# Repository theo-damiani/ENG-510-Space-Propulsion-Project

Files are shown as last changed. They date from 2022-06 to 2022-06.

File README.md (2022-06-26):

## SPACE PROPULSION – ENG-510 - Course project

### Main objectives:

- Practical application of the course content.
- Development of a **1.5 stage launcher**, i.e. 1 core + booster(s).
- Propulsion systems based on liquid propulsion (water + air pressure).
- Launcher shall integrate a recovery system (parachutes)
- Test equipment will be provided for propulsion systems testing and systems qualification. Ground station will also be provided.

### 31.5.2022: Lift-off:

<p align="center">
  Final Rocket
</p>

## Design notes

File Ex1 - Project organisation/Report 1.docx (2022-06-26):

- Launcher System (Technical coherence, requirement engineering) Romane
- Core Stage (Propulsion, mechanical engineering) Valentin
- Booster Stage (Propulsion, separation engineering, mechanism) Bruno
- Recovery System (Software, electrical engineering, mechanism) Noah
- Ground System I/F (Interface management, mechanism, certification) Théo

Main requirements (must be verifiable):

- The vehicle should reach a maximum apogee of 200m
- The main core stage should land under a parachute
- The booster should detach from the center core after their burn
- The propulsion should be only done by water and air

Mission phases - Concept of operation:

- Avionics powers in
- Countdown
- Liftoff
- End of burn of boosters
- Booster separation
- Apogee reached of the center core
- Center core’s parachute deployment
- Landing of the center core

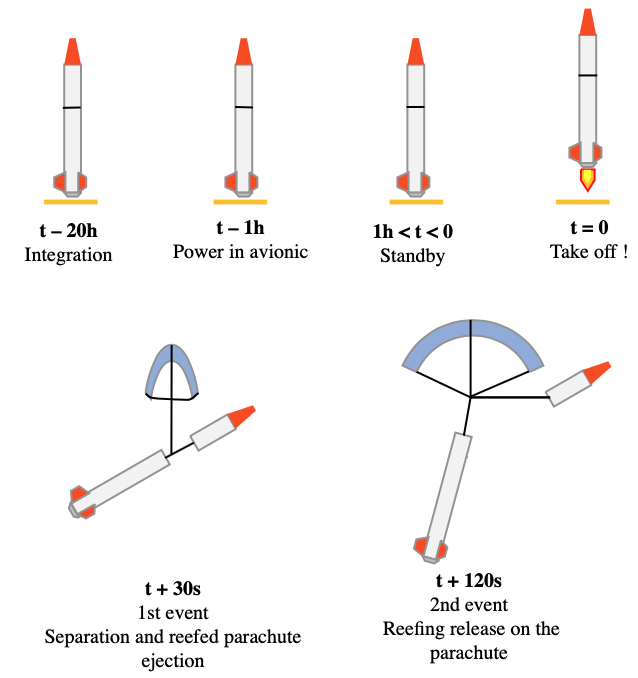
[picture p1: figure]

(to update, in progress… )

Verification to be performed

Schedule with short description of main task

08.03.2022 - Organization of the Project (Phase 0)

- Mission characterization
- Mission evaluation
- Requirements Definition
- High level specifications

22.3.2022 - Define Ground I/F

5.4.2022 - Performance Analysis

26.4.2022 -Verification Plan

10.5.2022 - Qualification Review

24.5.2022 - Lift-off

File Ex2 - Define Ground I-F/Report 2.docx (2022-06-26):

How many stages / bottles do we need ?

- main stage
- 3 bottles as side boosters

Which pressure do we foresee ?

- ca 10 bars (initial pressure)

Which Water mass is considered ?

How do you intend to fill the Water and when (on the launch pad) ?

Is there a need for a launch tower ?

Do we need a pressure measurement for your electrical system ?

Anything else ? Recovery ?

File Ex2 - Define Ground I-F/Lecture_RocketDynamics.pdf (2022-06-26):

# Rocket Dynamics

## - Forces on the Rockets - Drag - Rocket Stability - Rocket Equation - Specific Impulse - Rocket Motors

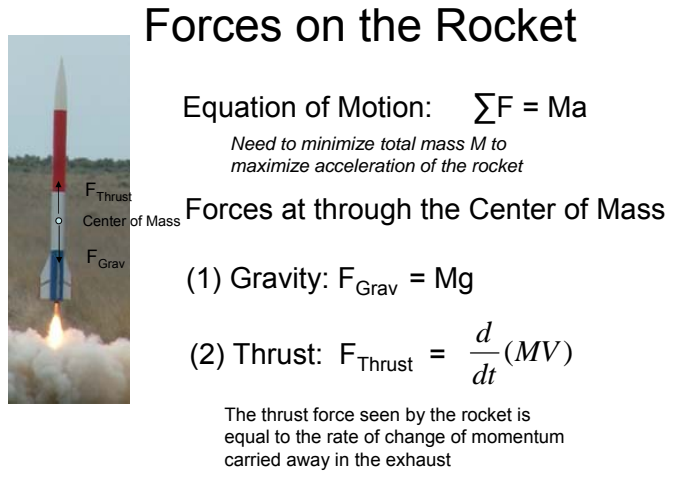
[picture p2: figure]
Forces on the Rocket; Equation of Motion:; (1) Gravity: FGrav = Mg; FGrav; (2) Thrust: FThrust =; (MV) dtd; FThrust; The thrust force seen by the rocket is equal to the rate of change of momentum carried away in the exhaust; Need to minimize total mass M to maximize acceleration of the rocket

## Center of MassForces at through the Center of Mass

## Thrust:

Assuming that the propellant speed is approximately constant then

## MPCE F

Thrust =

Where CE is the speed of the exhaust
is the rate of change propellant mass MP

In other words, how fast you go is dependent on
- the speed of the propellant
- the mass available in propellant

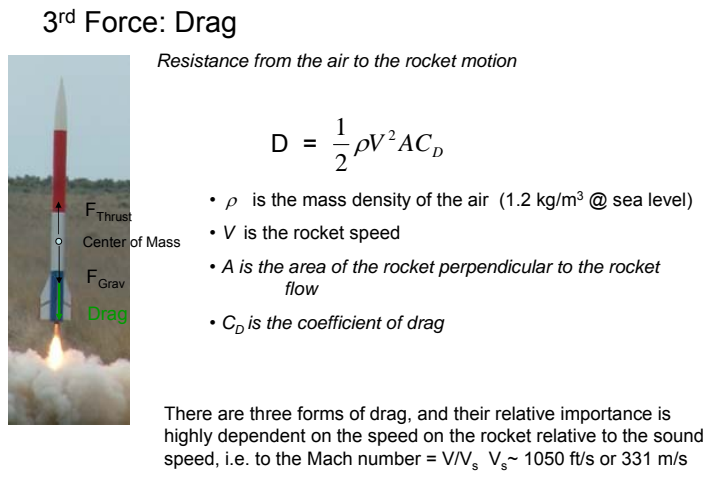
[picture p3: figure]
3rd Force: Drag; V ACD 2 21 D =; • V is the rocket speed; flow; • CD is the coefficient of drag; Center of Mass; FGrav; FThrust; Drag

- ρ is the mass density of the air (1.2 kg/m³ @ sea level)
- A is the area of the rocket perpendicular to the rocket

Resistance from the air to the rocket motion

There are three forms of drag, and their relative importance is highly dependent on the speed on the rocket relative to the sound speed, i.e. to the Mach number = V/Vs Vs~ 1050 ft/s or 331 m/s

# Types of Drag

### 1. Skin friction arises from the friction of the fluid against the

"skin" of the object that is moving through it. Skin friction arises from the interaction between the fluid and the skin of the body.

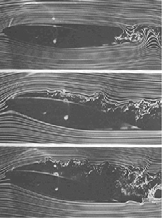
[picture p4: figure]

Rivets on skin surface add significantly to total drag at supersonic speeds

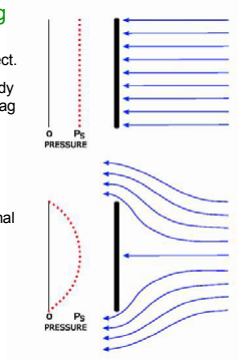
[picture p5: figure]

arises because of the form of the object. The general size and shape of the body is the most important factor in form drag Bodies with a larger apparent cross-section will have a higher drag than thinner bodies.
Sleek designs, or designs that are streamlined and change cross-sectional area gradually are also critical for achieving minimum form drag.

### (2) Pressure Drag or Form Drag

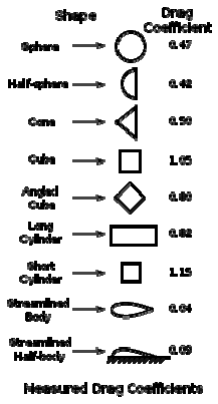
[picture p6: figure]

Drag coefficients for different shapes.

Elimination of vortices in the wake reduce the drag

### (2) Pressure Drag or Form Drag

## Wave drag

- is caused by the formation of shock waves around the aircraft which radiate away a considerable amount of energy producing enhanced drag
- Although shock waves are typically associated with supersonic flow, they can form at much lower speeds at areas on the aircraft where local airflow accelerates to supersonic speeds.

•The effect is typically seen at transonic speeds above about Mach 0.8, but it is possible to notice the problem at any speed over that of the critical Mach of that aircraft's wing.

•The magnitude peaks at about four times the normal subsonic drag.

•It is so powerful that it was thought for some time that engines would not be able to provide enough power to easily overcome the effect, which led to the concept of a "sound barrier".

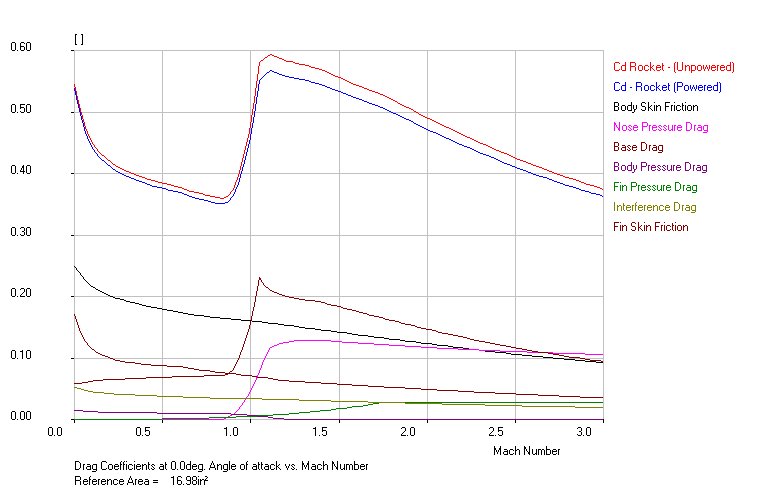
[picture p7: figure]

If you can get the rocket higher in altitude before going to high speed, effects from drag can be minimized

# Rocket Stability

### - Small perturbations will kick the rocket out of alignment - Active control of thrust vector could be used to correct these perturbations

– Heavy and Expensive

### - Passive control system through the use of fins - Success depends on the relative position of the Center of Pressure relative to the Center of Mass

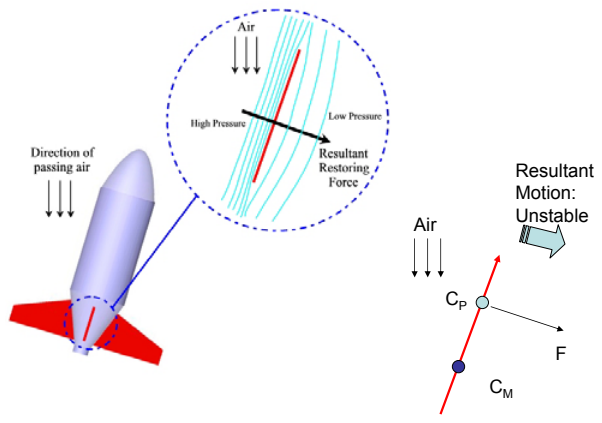
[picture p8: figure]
Air; Resultant Motion: Unstable
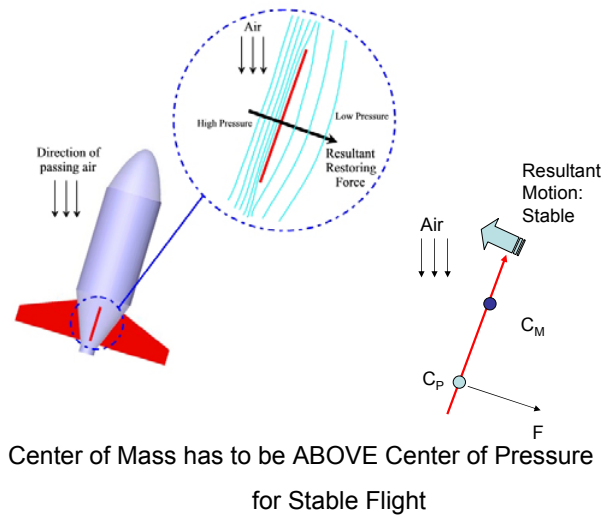
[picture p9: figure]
Air; Resultant Motion: Stable; for Stable Flight

### Center of Mass has to be ABOVE Center of Pressure

# Rocket Equation

Neglecting drag the equation of motion for the rocket is:
VE dt dM dt dV M | =

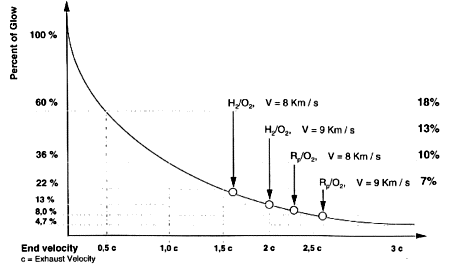
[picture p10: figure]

ò | ò =

M f

M

E

V

V | M

## dM dV V

0

2

1

## ln( ) ⁰

F

E | M
M ΔV =V | OR | exp( | ) ⁰
F | VE

V
M
M | Δ
= | -

Fraction of Payload becomes exponential small when required ΔV exceeds velocity of the propellant

Percentage Payload to Orbit Using
(1) H²/O2 and (2) Rp (highly refined kerosene)/O2

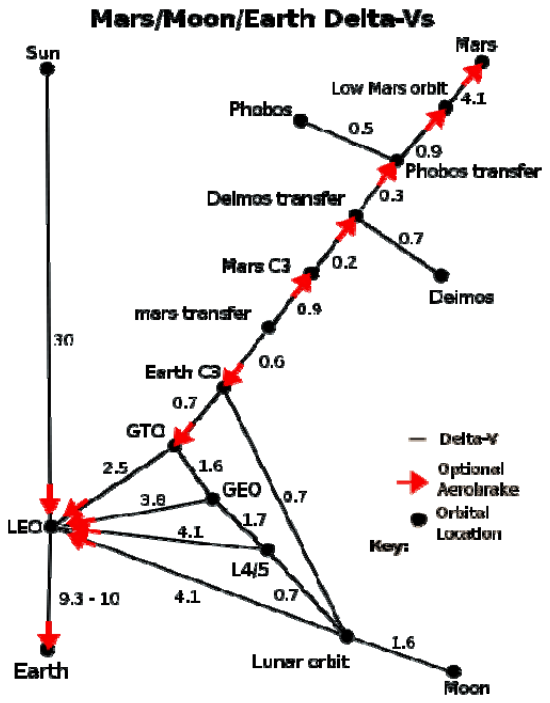
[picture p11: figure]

# Specific Impulse (Isp)

- is a way to describe the efficiency of rocket and jet engines.
- It represents the impulse (change in momentum) per unit of propellant.
- The higher the specific impulse, the less propellant is needed to gain a given amount of momentum.

g

V

## g mdt

## V mdt g mdt

## Fdt

Isp | E E = | = | = òò òò |

Specific impulse of various propulsion technologies

Ion thruster | 29,000 | 3,000 | 430
Bipropellant | 4,400 | 450 | 9.7
liquid rocket
Solid rocket | 2,500 | 250 | 3
Turbofan jet | 2,900 | 3,000 | ~0.05
engine | | | Energy per kg of exhaust (MJ/kg)
Specific
impulse
(s)

"Ve" exhaust
velocity
(m/s)

Engine

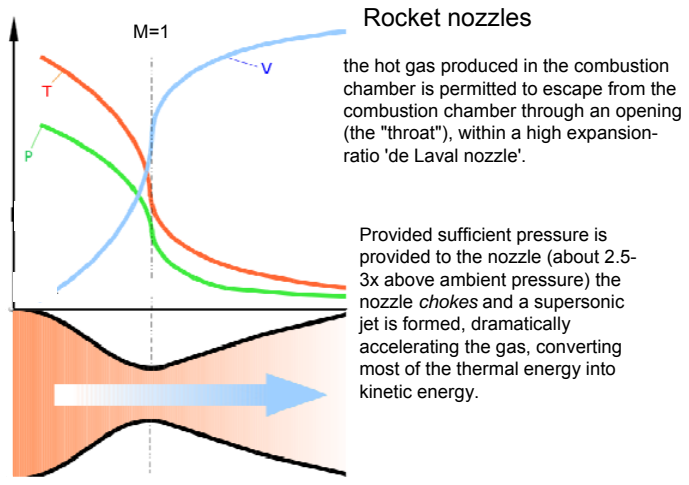
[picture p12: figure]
Rocket nozzles; the hot gas produced in the combustion chamber is permitted to escape from the combustion chamber through an opening; ratio 'de Laval nozzle'.; Provided sufficient pressure is provided to the nozzle (about 2.5- 3x above ambient pressure) the nozzle chokes and a supersonic jet is formed, dramatically accelerating the gas, converting most of the thermal energy into kinetic energy.

(the "throat"), within a high expansion-

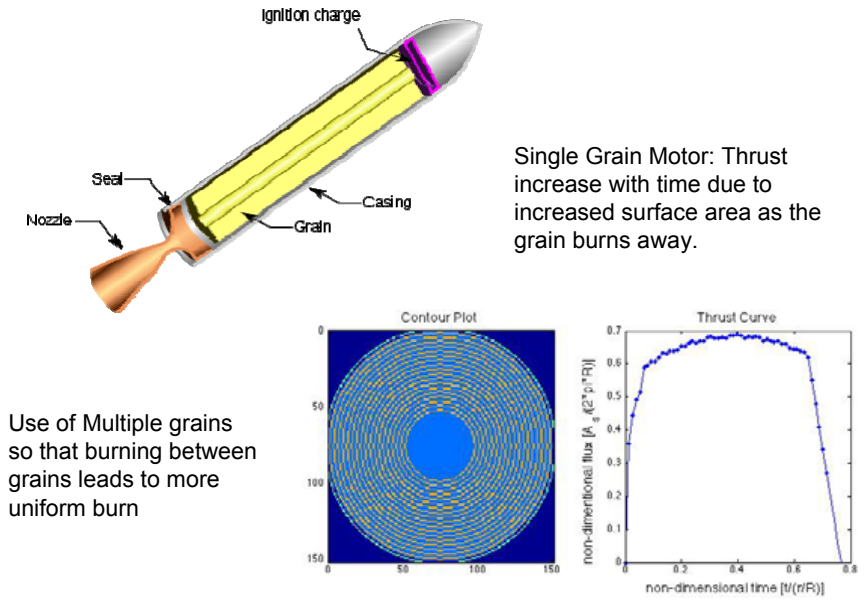
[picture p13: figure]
Single Grain Motor: Thrust increase with time due to increased surface area as the grain burns away.; Use of Multiple grains so that burning between grains leads to more uniform burn

Pumps needed for high performance are expensive to design, huge thermal fluxes across combustion chamber wall can impact reuse, failure modes include major explosions, a lot of plumbing is needed.

Up to ~99% efficient
combustion with
excellent mixture
control, throttleable,

Two fluid (typically liquid) propellants are
introduced through
injectors into combustion
chamber and burnt

Liquid
Bipropell
ant rocket

catalysts can be easily contaminated, monopropellants can detonate if contaminated or provoked, Isp is perhaps 1/3 of best liquids

Simple in concept,
throttleable, low
temperatures in
combustion chamber

Propellant such as
Hydrazine, Hydrogen
Peroxide or Nitrous
Oxide, flows over catalyst and exothermically
decomposes

Monopro
pellant
rocket

Some oxidisers are monopropellants, can explode in own right; mechanical failure of solid propellant can block nozzle (very rare with rubberised propellant), central hole widens over burn and negatively affects mixture ratio.

Quite simple, solid fuel
is essentially inert
without oxidiser, safer;
cracks do not escalate,
throttleable and easy to
switch off.

Separate oxidiser/fuel,
typically oxidiser is liquid and kept in a tank, the
other solid with central
hole

Hybrid
rocket

Once lit, extinguishing it is difficult although often possible, cannot be throttled in real time; handling issues from ignitable mixture, lower performance than liquid rockets, if grain cracks it can block nozzle with disastrous results, cracks burn and widen during burn.

Simple, often no
moving parts,
reasonably good mass
fraction, reasonable Isp.
A thrust schedule can
be designed into the
grain.

Ignitable, self sustaining solid fuel/oxidiser mixture ("grain") with central hole and nozzle

Solid
rocket
Type | Description | Advantages | Disadvantages | Solid Rocket Motors

# Solid Rocket Motors

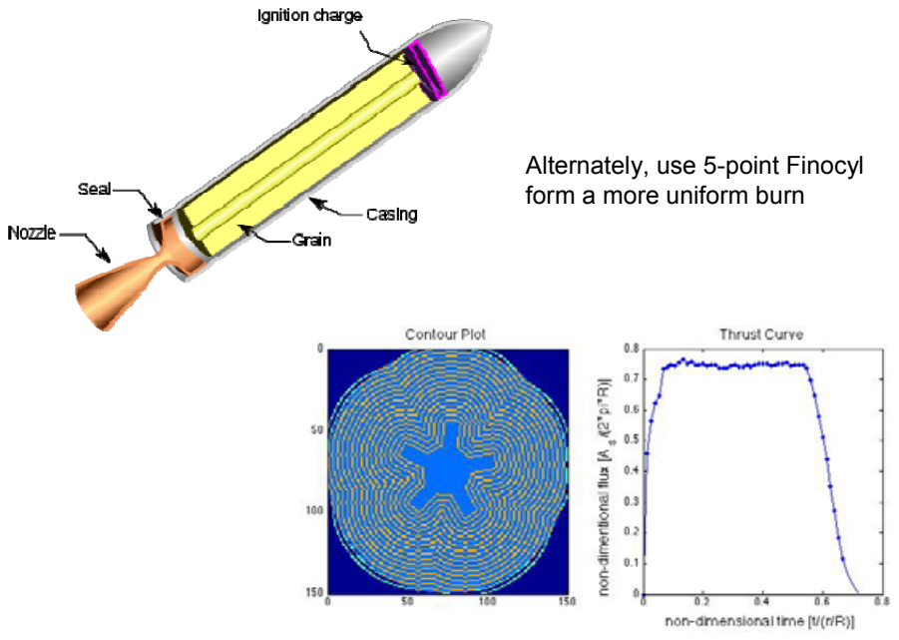
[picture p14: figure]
Alternately, use 5-point Finocyl form a more uniform burn

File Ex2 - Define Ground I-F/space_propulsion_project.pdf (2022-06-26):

## Space Propulsion Project - Group 2

Bruno Liard, Noah Kaltenrieder, Romane Belda, Theo Damiani, Valentin Cherrey, Lukas Stuber ´ EPFL Lausanne, Switzerland March 29, 2022

Abstract—This report is part of the Space propulsion course by Jager Markus Hendrik. The main objective of this course ¨ is to provide an overview of space propulsion systems and to describe the basic design principles of propulsion systems. The aim of the project is to develop a 1.5 stage launcher based on liquid propulsion. This report responds to the second exercises of March 22, 2022: Definition of the main characteristics of the rocket and the ground support equipment.

I. MAIN SPECIFICATION OF THE ROCKET
The core stage of the rocket will be composed of two bottles. One bottle for the propulsion mechanism and the other to place the necessary hardware and the parachute. To validate the requirements FCT-01, FCT-02, and FCT-03, the core stage must have a smaller thrust than the boosters but longer. So when boosters are burned out, they can get detached from the core stage which will still provide thrust to the rocket.
The burn time of the boosters depends on the cross area of the orifice. The natural throat of a plastic bottle is its opening. It is most resistive to stress in its natural state. That means it is easiest if the throat of the boosters does not need to be modified. However we want the boosters to burn less long than the core stage. To achieve that the size of the boosters is chosen to 1.5L and that of the core stage to 2L. This setup should ensure a longer burn time of the core stage even with equal orifices.
Additionally, the pressure inside the boosters is chosen higher than that in the core stage (8 bars for the core stage and 10 bars for the boosters).
The center of mass needs to be above the center of pressure to ensure a stable flight. This sets another requirement for the core stage. It needs to have enough mass in the top and/or the mass needs to be sufficiently high to raise the center of mass above the center of pressure. This requirement needs to be fulfilled for both phases of the burn: while the boosters are attached to the core stage and after separation. The boosters are attached at the bottom of the rocket and increase the drag considerably but they also add a lot of mass at the bottom of the rocket. This needs to be reflected in the design.
For more stability, the boosters will be attached to the top and bottom of the core stage. The first idea is to crop straws into small pieces (2 or 3 cm) and fix them to the core stage with highly resistant duct tape or glue. On the other hand, 2 U-shaped fence nails (so-called agraffe) will be put on each booster. Those u-shaped pins are the proper dimension: around 30mm in length and 2mm diameters and they are strong enough to not bend against the weight of the core stage. Adjustments remain possible during the construction phase of the rocket if difficulties or worries occur.
We will try to make the nose cones of the boosters and core stage more aerodynamic by using duct tape or putting a piece sharper like the top of another bottle. Additionally, in the nose cone of the core stage, some weights will be put to move forward the center of gravity and gain vertical stability.

Figure 1. Schema of the rocket

II. WATER QUANTITY/AIR PRESSURE
Matlab | simulations | have | been | used | in
order | to | play | with | the | different | parameters
we can choose, namely the
volume of the bottles, the air
pressure in both boosters and
core stage, the quantity of water with which they are filled, but also the area of the throats, in order to find the maximum altitude the rocket could reach. The maximum pressure in the bottles has been set to 10 bars
for the moments but solutions
to reinforce the bottles will be

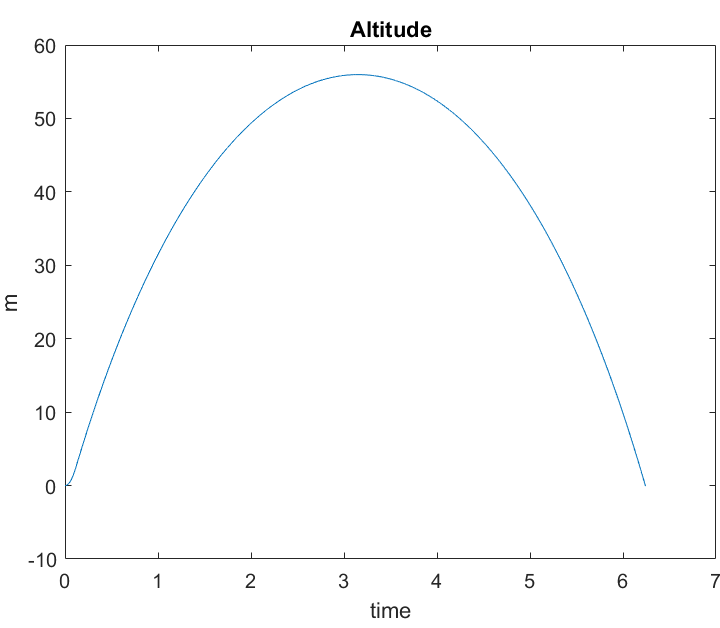
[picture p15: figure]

studied. The optimum filling rate is around 45% of the bottle capacity, which implies as a first approximation 0.65kg of water in the boosters and 0.9kg of water in the core stage.

III. WATER FILLING AND PRESSURIZATION
The booster and the core stage can be filled with water before the launch. However, they will be pressurized only before liftoff to avoid any loss and to follow the planned trajectory as closely as possible.

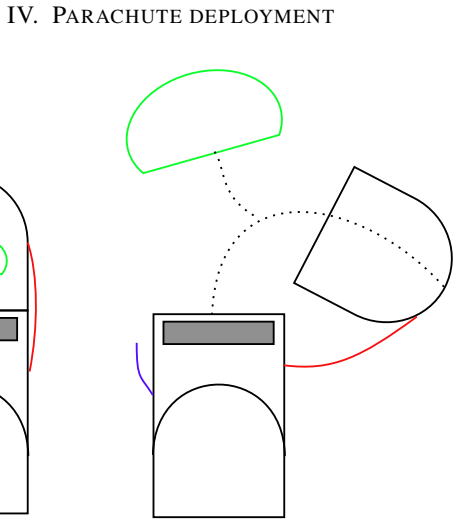
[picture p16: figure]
IV. PARACHUTE DEPLOYMENT

Figure 2. Schematic of the parachute deployment: left side during the ascent phase, right side after the deployment

The upper stage of the rocket will be split into 2 parts: one to hold the hardware (raspberry pi and sensor) and the other the parachute (in green in the figure 2). The top section will be connected to the rocket by rubber bands (red and blue lines Fig.2) on each side of the rocket. A rope (dashed line Fig.2) will link the center of the 2 parts. The parachute will be attached to this rope with a metal ring (requirement DGN-02), so when the raspberry will detect the apogee of the rocket, it will trigger a motor that will free up one of the elastic bands. The top section will be released allowing the parachute to be deployed.
A possible motor for this task is shown in figure 3.
V. HARDWARE NEEDED
A Raspberry Pi Pico will be needed to notice when the rocket has reached its apogee and deploy the parachute. For the Raspberry we’ll use a header and the Grove shield for Pico, with some Grove cables to connect the sensors to the card. A barometer can be used to detect when the air pressure starts to rise again or an accelerometer to calculate when the vertical velocity is zero. The raspberry, sensor, and, parachute will be put in the upper stage of the core stage. A motor will cut one of the elastic bands.

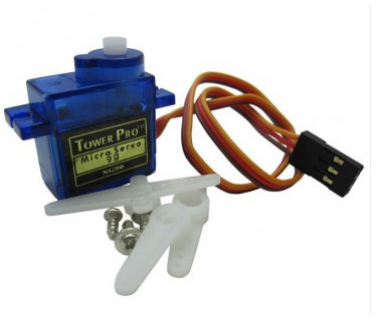
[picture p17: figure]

Figure 3. Micro Servo Motor to cut the elastic band

VI. LAUNCHPAD SPECIFICATION

Items | Weight in g.
2L soda bottle x2 1.5L soda bottle x2 Raspberry pi pico Barometer GPIO header Motor Straws U-shaped nials x4 Nylon Rope Ø5 mm (0.013 kg/m) Parachute Duck tape Metal Ring Rubber band x2 | 53 x2 40 x2 3 TBD TBD 9 0.40 1.8 x4 13 TBD TBD 6 2.8 x2
Total | 221.2

Table I
PRELIMINARY ESTIMATION OF THE DRY MASS OF THE ROCKET.

Ref | Description | Verification method
MS-01 | The launch vehicle shall reach an apogee between 10 m to 200 m (AGL) | On-board altitude measure-ment
MS-02 | The launch vehicle shall deploy a parachute | Ground test of deployment
MS-03 | The launch vehicle shall have a safe landing, such that it can be reused without any modification | Visual inspection after landing
MS-04 | The launch vehicle shall be aerodynamically stable at launch rail exit and during flight | Design
FCT-01 | All propulsion systems shall initiate at lift-off | Design
FCT-02 | All propulsion systems shall exclusively use water and either air or nitrogen for pressurization | Design, visual confirmation during launch pad operations
FCT-03 | If applicable, booster stage shall be discarded at “burnout” (i.e. as soon as no more thrust is generated) | Design
FCT-04 | Maximum pressure allowed for COTS pressure vessels at launch is [7] bar | Design, will be regulated by GSE operators
FCT-05 | Max pressure for modified COTS or SRAD pressure vessels at launch is [18] bar | Design, will be regulated by GSE operators
DGN-01 | Avionics shall be powered only once the launch vehicle is sitting on the launch pad | Design
DGN-02 | Parachute shall be attached/detached to/of the rocket using a metal ring | Design
CONF-01 | The launch vehicle shall be either single stage or 1.5 stage, i.e. 1 core stage or 1 core stage + booster(s) | Design
CONF-02 | If applicable, booster total number shall not be greater than [3] | Design
CONF-03 | If applicable, booster shall be uniformly spread around the core stage | Design
PHY-01 | Airframe/pressure vessels shall possess a standard thread | Design
PHY-03 | The maximum dry mass of the launch vehicle shall be [1.5] kg | Measurement
PHY-04 | The maximum height of the launch vehicle shall be [120] cm | Measurement
SAF-01 | No pyrotechnics (e.g. black powder) shall be used | Design
INT-01 | Launch vehicle shall fit on the launch rail profile | Design, possibility to test-fit beforehand
INT-02 | Propulsion systems shall fit on the GSE pressurization fitting | Design, possibility to test-fit beforehand
VF-01 | All propulsion systems (core stage + boosters if applicable) shall perform at least [one] successful static fire | Test, measurement
VF-02 | All modified COTS pressure vessels shall pass a hydrostatic pressure test at 1.5x the nominal launch pressure | Test, measurement
VF-03 | Calculation/simulation of thrust generated by each stage shall be provided prior to lift-off | Calculation and analysis
VF-04 | Calculation/simulation of flight trajectory of the launch vehicle shall be provided prior to lift-off | Calculation and analysis

Table II
TECHNICAL REQUIREMENTS TO FOLLOW. A GREEN LINE MEANS THAT IT HAS BEEN VERIFIED.

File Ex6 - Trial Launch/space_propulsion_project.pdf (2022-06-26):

## Space Propulsion Project - Group 2

Bruno Liard, Noah Kaltenrieder, Romane Belda, Theo Damiani, Valentin Cherrey, Lukas Stuber ´ EPFL Lausanne, Switzerland June 26, 2022

Abstract—This report is part of the Space propulsion course by Jager Markus Hendrik. The main objective of this course ¨ is to provide an overview of space propulsion systems and to describe the basic design principles of propulsion systems. The aim of the project is to develop a 1.5 stage launcher based on liquid propulsion. This report responds to the final exercise of May 24, 2022: Trial Launch.

I. TRIAL LAUNCH RESULT

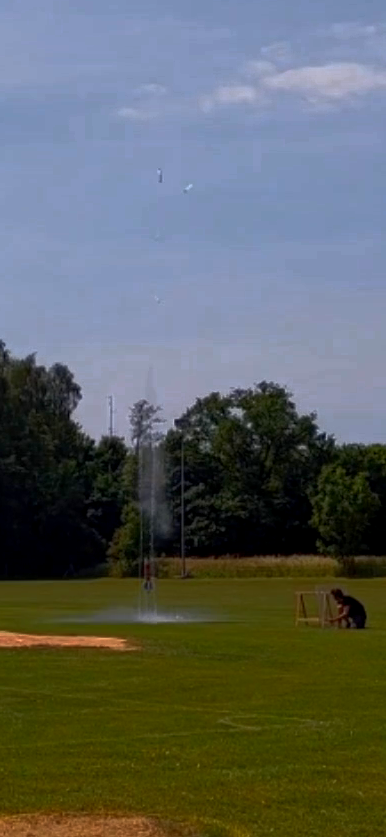
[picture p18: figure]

Figure 1. Lift off.

In Figure 1, we can see the start of the lift-off. In the sky, we can distinguish the two boosters and the core stage still on the launch rail. Thus the main problem in this part of the launch is the booster separations. Indeed, the booster’s thrusts were too powerful and then the boosters detached themselves from the core stage. Thus the core stage remains alone and even if it succeeds to lift off, it could not achieve the desired vertical trajectory and altitude targeted.

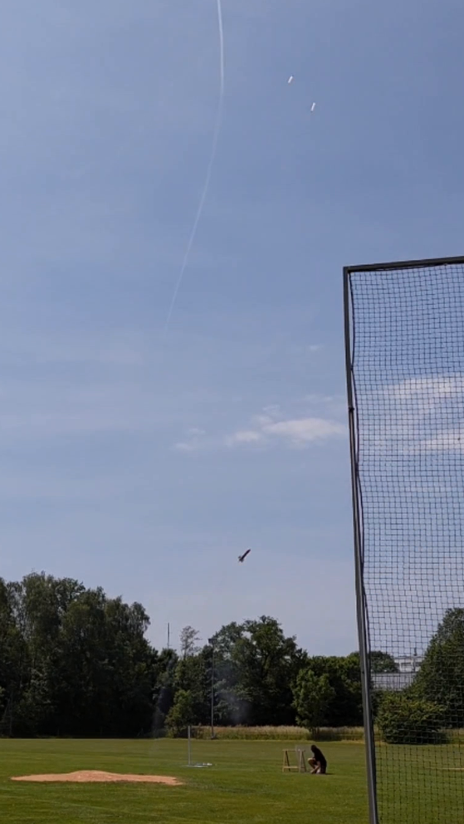
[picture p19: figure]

Figure 2. Core stage leaving the launch rail.

Another problem the rocket faced is after leaving the launch rail (Figure 2). We can see that the core stage is not going vertically. This must be a problem with the center of pressure and mass. We did not want to add too much weight to the nose cone because we feared that the parachute would not be deployed as in our current design the whole nose cone is pulled on the side of the rocket to free the parachute. Finally, before lift-off, the elastic of the parachute deployment system detach by itself on the launch pad. We however accepted to launch knowing this problem, because we did not want to loose a lot of time to refill all the bottles.

II. MODIFICATIONS ON THE ROCKET
- Boosters problem:
The pins attachment system should be more resistant. In fact, the gluing surface was small and the male pins were too weak to withstand the force due to the difference of thrust of the booster and the central core. To address this problem, the final version will be a full crone around the center core to get more gluing surface and the pins will be made bigger.
- Stability problem: To mitigate this problem, we will add for the final launch around 100g of sand in the nosecone to move forward the CG and getting more stability.
- Parachute deployment modification: The parachute deployment mechanism was not robust enough to hold the thrust and instability of the rocket while remaining reliable. So the team is working on a new, more solid system: with spring and PVC cylinder instead of elastics and plastic bottles. In addition, a radial deployment system is constructed. This second system would allow us to put more weight on the nose cone.

III. POSITIVE RESULT
From this launch trial, we get validation on different aspects. First of all, the choice in the quantity of water, air pressure, and the nozzle were right, during the launch booster’s burns were much faster than the core stage. Therefore if the boosters were stay attached to the rocket, they would have greatly helped the core stage before getting separated.
The fins were of the right size. They kind of succeeded to keep a small stability even if the nose cone of the rocket were really too light and the exiting rail velocity were too low.
The raspberry worked correctly and recorded some information about the flight.
The rocket was strong enough to ensure a ”hard landing”, only the nose cone was crushed. The core stage and hardware section of the rocket were not damaged at all.

Ref | Description | Verification method
MS-01 | The launch vehicle shall reach an apogee between 10 m to 200 m (AGL) | On-board altitude mea-surement
MS-02 | The launch vehicle shall deploy a parachute | Ground test of deploy-ment
MS-03 | The launch vehicle shall have a safe landing, such that it can be reused without any modification | Visual inspection after landing
MS-04 | The launch vehicle shall be aerodynamically stable at launch rail exit and during flight | Design
FCT-01 | All propulsion systems shall initiate at lift-off | Design
FCT-02 | All propulsion systems shall exclusively use water and either air or nitrogen for pressurization | Design, visual confir-mation during launch pad operations
FCT-03 | If applicable, booster stage shall be discarded at “burnout” (i.e. as soon as no more thrust is generated) | Design
FCT-04 | Maximum pressure allowed for COTS pressure vessels at launch is [7] bar | Design, will be regu-lated by GSE operators
FCT-05 | Max pressure for modified COTS or SRAD pressure vessels at launch is [16] bar | Design, will be regu-lated by GSE operators
FCT-06 | If applicable, core stage and booster stage shall be pressurized at the same pressure value | Design
DGN-01 | Avionics shall be powered only once the launch vehicle is sitting on the launch pad | Design
DGN-02 | Parachute shall be attached/detached to/of the rocket using a metal ring | Design
DGN-03 | If applicable, all booster and core stage shall have their nozzle/water exit at the same height | Design
CONF-01 | The launch vehicle shall be either single stage or 1.5 stage, i.e. 1 core stage or 1 core stage + booster(s) | Design
CONF-02 | If applicable, booster total number shall not be greater than [3] | Design
CONF-03 | If applicable, booster shall be uniformly spread around the core stage | Design
PHY-01 | Airframe/pressure vessels shall possess a standard thread | Design
PHY-03 | The maximum dry mass of the launch vehicle shall be [1.5] kg | Measurement
PHY-04 | The maximum height of the launch vehicle shall be [120] cm | Measurement
SAF-01 | No pyrotechnics (e.g. black powder) shall be used | Design
INT-01 | Launch vehicle shall fit on the launch rail profile | Design, possibility to test-fit beforehand
INT-02 | Propulsion systems shall fit on the GSE pressurization fitting | Design, possibility to test-fit beforehand
VF-01 | All propulsion systems (core stage + boosters if applicable) shall perform at least [one] successful static fire | Test, measurement
VF-02 | All modified COTS pressure vessels shall pass a hydrostatic pressure test at 1.1x the nominal launch pressure | Test, measurement
VF-03 | Calculation/simulation of thrust generated by each stage shall be pro-vided prior to lift-off | Calculation and analysis
VF-04 | Calculation/simulation of flight trajectory of the launch vehicle shall be provided prior to lift-off | Calculation and analysis

Table I
TECHNICAL REQUIREMENTS TO FOLLOW. A GREEN LINE MEANS THAT IT HAS BEEN VERIFIED.

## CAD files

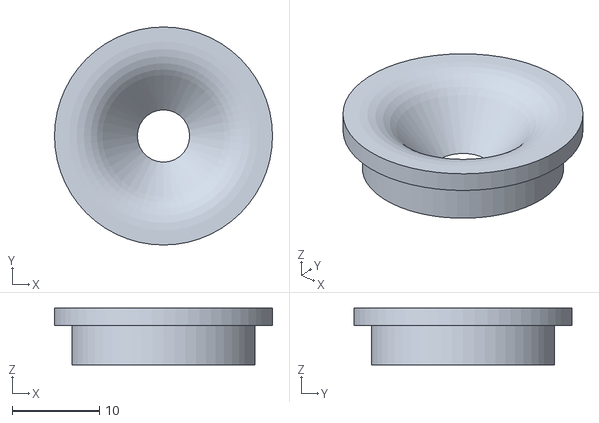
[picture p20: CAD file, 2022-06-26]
Ex4 - Verification plan/nozzle.stl
25.0 x 25.0 x 6.50

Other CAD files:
Ex4 - Verification plan/nozzle.CATPart

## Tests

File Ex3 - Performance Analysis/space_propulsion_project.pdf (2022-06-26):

## Space Propulsion Project - Group 2

Bruno Liard, Noah Kaltenrieder, Romane Belda, Theo Damiani, Valentin Cherrey, Lukas Stuber ´ EPFL Lausanne, Switzerland April 26, 2022

Abstract—This report is part of the Space propulsion course by Jager Markus Hendrik. The main objective of this course ¨ is to provide an overview of space propulsion systems and to describe the basic design principles of propulsion systems. The aim of the project is to develop a 1.5 stage launcher based on liquid propulsion. This report responds to the second exercises of April 5, 2022: performance analysis of our water rocket.

I. COMPUTATION EQUATIONS

Here are the list of the assumptions made to simplify the computations:
- air is an ideal gaz and the process is adiabatic
- variation of bottle’s pressure is an adiabatic process
- water is incompressible
- no losses at the throat (Bernouilli useable)
- no thrust given by the air at the end of burn
- negligible mass of air
- the rocket is going straight following the z axis
- constant speed during parachute descent

The Bernoulli equation describes the state of a streamline starting at the top surface of the water inside the bottle and ending at the exit of the nozzle:

Pbottle

ρwater

+ gz +

1
2

v

2
inbottle =

Pnozzle

ρwater

+ gz +

1
2

v

2
exit (1)

The difference of height (term z) is at most the height of a plastic bottle, i.e. 20cm. Thus it can be neglected. Equation 1 shortens to:

Pbottle

ρwater

+

1
2

v

2
inbottle =

Pnozzle

ρwater

+

1
2

v

2
exit | (2)

The expression of the mass flow in 1D:

m˙ = vexit ·Anozzle · ρwater = vinbottle ·Abottle · ρwater (3)

Which gives a relation for the different speeds:

vexit · Anozzle = vinbottle · Abottle | (4)

Note that this relationship is time-independent. Combining equations 2, 3 and 4 gives an expression for the mass flow:

m˙ (t) = Athroat · Abottles
2 · ρwater(Pbottle(t) − Pnozzle)
A²

bottle − A²
nozzle
(5)

We can simplify the denominator with the assumption that the area of the throat is negligible compared to the much bigger area of the bottle. This is equivalent to putting the speed inside the bottle to zero. The mass flow becomes.

m˙ simp(t) = Athroatp
2 · ρwater(Pbottle(t) − Pnozzle) (6)

Note that this expression is time-dependent. The pressure inside the bottle will decrease with time, as will the mass flow.
The force exerted on the rocket by an engine is given by:

Fengine = λ · ( ˙m · vexit + (Pexit − Patm) · Anozzle) (7)

Where λ is the the nozzle efficiency, vexit and Pexit the speed and the pressure of the water when it leaves the nozzle. In the case of water we can assume that the exit pressure in the nozzle is equal to the atmospheric pressure. The thrust simplifies to:

Fthrust =λ · m˙ (t) · vexit(t)
=λ · v

2
exit(t) · Anozzle · ρwater

=λ · 2 · Anozzle · (Pbottle(t) − Patm)

(8)

Then the overall force acting on the rocket is:

Ftotal = Fthrust − Fgravity − Fdrag | (9)

Where
Fgravity = m(t) · g | (10)

Fdrag =

1
2

Cd · ρwater · v

2
rocket(t) · Arocket | (11)

With the force we can calculate the acceleration:

a(t) = Fthrust(t) − Fgravity(t) − Fdrag(t) m(t) | (12)

To calculate the time dependent parameters, a time step dt is introduced. In a simulation the parameters are recalculated after every time step.
By integration we can compute the velocity and altitude at every timestep:
vi+1 = aidt + vi | (13)

zi+1 =

1
2
aidt² + vidt + zi | (14)

Then, at each step (dt) we compute again the volume, the pressure and the mass of the booster and center core. The equation is the volume of the air inside the bottle at any time during the burn phase:

Vi+1 = Vi +

m˙ i

ρwater

- dt | (15)

The equation is the pressure inside the bottle at any time during the burn phase by assuming an adiabatic process:

Pi+1 = Pi

- (

Vi

Vi+1

)

γ
(16)
A. ”State machine” of the simulation

The simulation works in four phases:

1) First phase starts at t = 0 and simulates the burn of the boosters and the core and finishes after the end of the burn of the boosters, which is equal to their separation with the center core.
2) Second phase starts after the separation until the end of the burn of the central core
3) Third phase simulates the balistic flight of the center core until the apogee
4) Last phase simulates the descent of the center core under its parachute

Below stand the graphs of the preliminary simulation of the flight of our rocket. A lot of constants are still not the final ones, such as the rocket’s mass, the area of the parachute, the quantity of water, the area of the throat...

II. RESULTS OF THE SIMULATION

In the following section, the results of the simulation are presented with the figures. We decided to fix the initial pressure at 7 bar. Therefore the requirement FCT-04 is respected and we do not have to re-enforce the water bottles. Then we tried to find the best parameters to achieve the higher possible altitude:

- Booster water volume: 0.7 L
- Core-Stage water volume: 0.9 L
- Dry-mass of the rocket: 230 g
- Core-Stage nozzle: 6 mm for the diameter
- Booster-Stage nozzle: 22mm for the diameter (no specific nozzle)

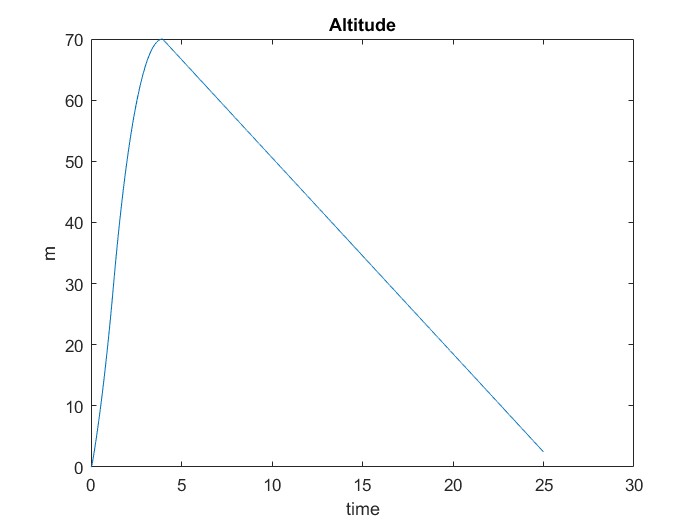
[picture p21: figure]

Figure 1. Altitude [m] over time [s]

The apogee of the rocket is approximately about 70m, the requirement (MS-01) is fulfill.

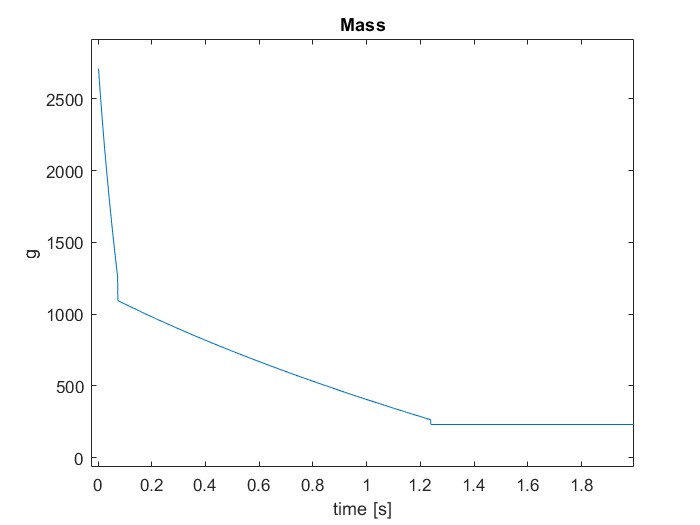
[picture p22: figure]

Figure 2. Mass [g] over time [s]

We can see the booster’s separation from the core stage at 0.1s. After this point, the slope is less steep because the core stage has a longer but slower thrust than the booster at the beginning. Near 1.25s, there is the last drop of the water of the core stage, then the slope is constant because there is only the dry mass without the boosters.

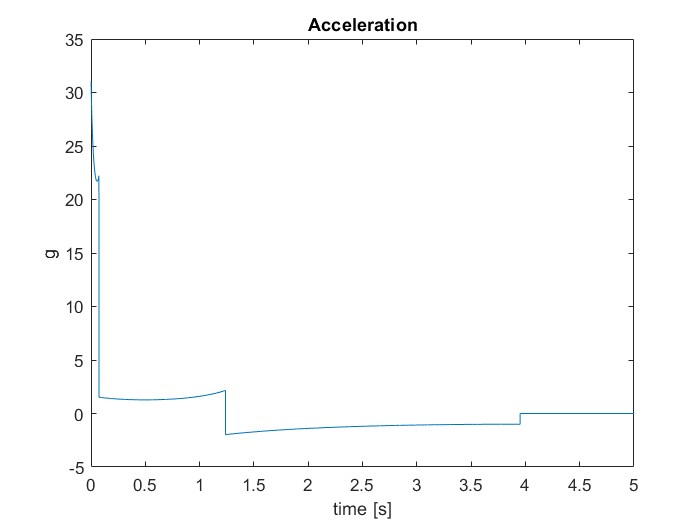
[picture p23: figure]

Figure 3. Acceleration [in g’s] over time [s]

There is the same step at 0.1s for the booster’s separation and at 1.25s for the end of the core stage burn. Then, the acceleration is negative have there are no more forces in the upper direction (towards the sky) and in approximation only the gravitational influence. Finally at 4s, the rocket reaches the apogee and the parachutes are deployed.

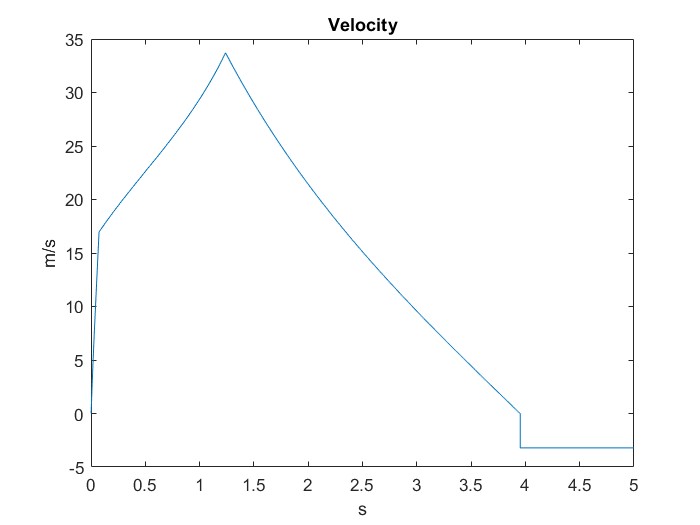
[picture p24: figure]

Figure 4. Velocity [m/s] over time [s]

Again at 0.1s, we can observe the difference in the velocity with and without the boosters. At 1.25s, the velocity starts decreasing, indeed the acceleration is now negative. And at 4s, after the apogee, the rocket is under its parachute at a constant negative velocity.

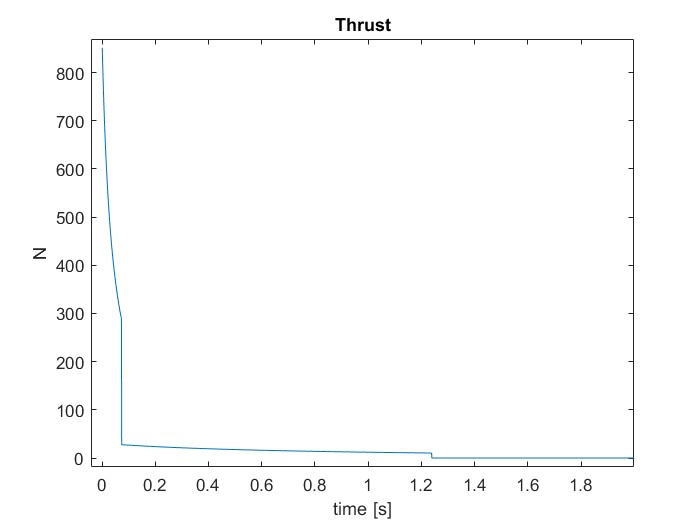
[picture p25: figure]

Figure 5. Thrust [N] over time [s]

For the last graphic, we plot only the pressure until 1.25s because, after the end of the burn of the rocket, the thrust remains null.

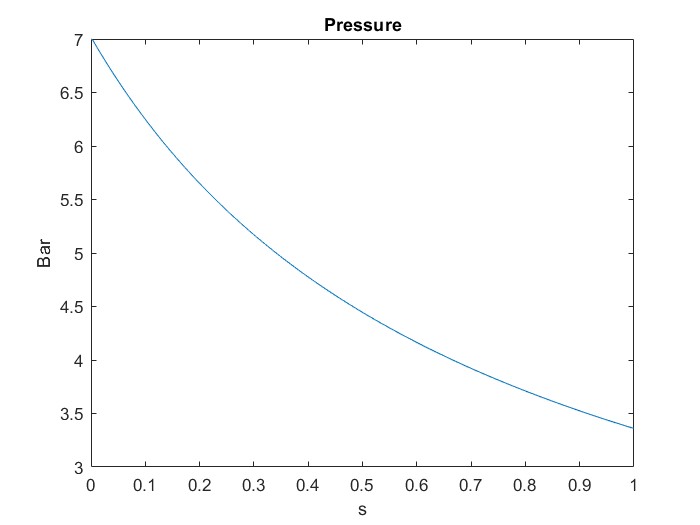
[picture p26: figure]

Figure 6. Pressure [bar] over time [s]

III. ADDITIONAL SPECIFICATION OF THE ROCKET
In this section, we described the new thinking involving design choices and materials specifications:
- The pins and tube between the core stage and boosters will be 3D printed.
- Epoxy glue will be used to fix the pins instead of duct tape.
- Ventilation holes (3mm diameter) on both sides of the upper part of core stage will be placed for the proper functioning of the barometer.
- Rubber bands will be tied to the inside of the hardware section of the core stage. Then small holes will allow the rubber bands to exit the main stage and be attached at the top of the rocket.
Items | Weight in g.
2L soda bottle x2 1.5L soda bottle x2 Raspberry pi pico Barometer GPIO header Servo Motor 3D printed pins Nylon Rope Ø5 mm (0.013 kg/m) Parachute Epoxy glue Rubber band x2 Portable battery | 53 x2 40 x2 3 TBD TBD 9 TBD 13 28 TBD 2.8 x2 77
Total | 326.2

Table I
UPDATED ESTIMATION OF THE DRY MASS OF THE ROCKET.

Ref | Description | Verification method
MS-01 | The launch vehicle shall reach an apogee between 10 m to 200 m (AGL) | On-board altitude mea-surement
MS-02 | The launch vehicle shall deploy a parachute | Ground test of deploy-ment
MS-03 | The launch vehicle shall have a safe landing, such that it can be reused without any modification | Visual inspection after landing
MS-04 | The launch vehicle shall be aerodynamically stable at launch rail exit and during flight | Design
FCT-01 | All propulsion systems shall initiate at lift-off | Design
FCT-02 | All propulsion systems shall exclusively use water and either air or nitrogen for pressurization | Design, visual confir-mation during launch pad operations
FCT-03 | If applicable, booster stage shall be discarded at “burnout” (i.e. as soon as no more thrust is generated) | Design
FCT-04 | Maximum pressure allowed for COTS pressure vessels at launch is [7] bar | Design, will be regu-lated by GSE operators
FCT-05 | Max pressure for modified COTS or SRAD pressure vessels at launch is [16] bar | Design, will be regu-lated by GSE operators
FCT-06 | If applicable, core stage and booster stage shall be pressur-ized at the same pressure value | Design
DGN-01 | Avionics shall be powered only once the launch vehicle is sitting on the launch pad | Design
DGN-02 | Parachute shall be attached/detached to/of the rocket using a metal ring | Design
CONF-01 | The launch vehicle shall be either single stage or 1.5 stage, i.e. 1 core stage or 1 core stage + booster(s) | Design
CONF-02 | If applicable, booster total number shall not be greater than [3] | Design
CONF-03 | If applicable, booster shall be uniformly spread around the core stage | Design
PHY-01 | Airframe/pressure vessels shall possess a standard thread | Design
PHY-03 | The maximum dry mass of the launch vehicle shall be [1.5] kg | Measurement
PHY-04 | The maximum height of the launch vehicle shall be [120] cm | Measurement
SAF-01 | No pyrotechnics (e.g. black powder) shall be used | Design
INT-01 | Launch vehicle shall fit on the launch rail profile | Design, possibility to test-fit beforehand
INT-02 | Propulsion systems shall fit on the GSE pressurization fitting | Design, possibility to test-fit beforehand
VF-01 | All propulsion systems (core stage + boosters if applicable) shall perform at least [one] successful static fire | Test, measurement
VF-02 | All modified COTS pressure vessels shall pass a hydrostatic pressure test at 1.5x the nominal launch pressure | Test, measurement
VF-03 | Calculation/simulation of thrust generated by each stage shall be provided prior to lift-off | Calculation and analysis
VF-04 | Calculation/simulation of flight trajectory of the launch vehicle shall be provided prior to lift-off | Calculation and analysis

Table II
TECHNICAL REQUIREMENTS TO FOLLOW. A GREEN LINE MEANS THAT IT HAS BEEN VERIFIED.

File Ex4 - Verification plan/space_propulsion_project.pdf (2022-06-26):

## Space Propulsion Project - Group 2

Bruno Liard, Noah Kaltenrieder, Romane Belda, Theo Damiani, Valentin Cherrey, Lukas Stuber ´ EPFL Lausanne, Switzerland May 3, 2022

Abstract—This report is part of the Space propulsion course by Jager Markus Hendrik. The main objective of this course ¨ is to provide an overview of space propulsion systems and to describe the basic design principles of propulsion systems. The aim of the project is to develop a 1.5 stage launcher based on liquid propulsion. This report responds to the fourth exercise of April 26, 2022: verification plan.

I. VERIFICATION OF THE MAIN REQUIREMENTS
A. Boosters separation
To ensure a nominal separation of the boosters and the center core, we firstly design and compute the burn time of the boosters in order to have a bigger thrust and a shorter burn than the main core. Secondly, the attachment of the boosters on the center core are designed to disconnect by itself (only by gravity) after the end of the burn.
B. Parachute deployment
The parachute deployment will be verified by triggering an impulsion of the Servo motor with the Raspberry, i.e. by sensing the increase of pressure after the apogee and with a backup timer. This way, the correctness of the opening and the deployment of the parachute will be verifiable in an elevator, or running up and down stairs for example (Yes it works very well, the EPFL Rocket Team is an expert with this testing process, particularly at 3am!).
C. Electronic systems
Each of the electronic systems (Raspberry Pi, Barometer, Accelerometer) will be isolated for testing. The Raspberry Pi is assumed to work as intended since we use it to verify the other systems.
The Servo motor will be verified to work correctly by simply triggering the rotation of the axis, to do that it will be connected to the Raspberry Pi.
The accelerometer can be verified for example by programming the Raspberry to log the data collected by the accelerometer every seconds, try to run or ride a bike and check the collected logs afterward.
The barometer can be tested by doing the same log system and try it in different altitudes or environment with different pression.
D. Safe-landing
First simple test:
We will take the main parts of our rocket, mainly the core stage, so the rocket without the electronic system to avoid breaking it. We will replace the weights of the electronic system by small dummy mass. Then we will deploy manually the parachute, just open the head of our rocket. Therefore to test the safe-landing, we will throw the rocket from a specific height. This test will also verify if the parachute opens correctly during the descent phase. To prevent damaging the rocket we will stand below the rocket with a bed sheet to recover the rocket as firemen. Moreover, by calculation the main core will have a terminal velocity less than 5m/s, which is the requirement for a reserve parachute for human.
Second test:
In this test, we will add the raspberry in the rocket and record the rocket’s acceleration. Then we will throw again the rocket and check that the velocity stay constant a certain time before touch the ground. And that this velocity is below the threshold given by: q 2·Mtot·g
ρ·Seff ·Cd
E. Maximal altitude (below 200m)
This test will be check by calculation. We will run a new simulation with our Matlab program with the precise mass of the rocket before the launch. And, we will also test it during the trial launch by analysing the data of the accelerometer and the pressure sensor.
F. Pressure test
This test just verifies if our vessel can support the pressure. We will test the pressure at 1.5x the nominal launch pressure.
G. Vertical Lift-Off
The vertical lift-off will be estimated by the calculation of the center of mass and the center of pressure with the software Open Rocket.

Items | Weight in g.
2L soda bottle x2 1.5L soda bottle x2 Raspberry pi pico Barometer GPIO header Servo Motor 3D printed pins Nylon Rope Ø5 mm (0.013 kg/m) Parachute Epoxy glue Rubber band x2 Portable battery | 53 x2 40 x2 3 TBD TBD 9 TBD 13 28 TBD 2.8 x2 77
Total | 326.2

Table I
UPDATED ESTIMATION OF THE DRY MASS OF THE ROCKET.

Ref | Description | Verification method
MS-01 | The launch vehicle shall reach an apogee between 10 m to 200 m (AGL) | On-board altitude mea-surement
MS-02 | The launch vehicle shall deploy a parachute | Ground test of deploy-ment
MS-03 | The launch vehicle shall have a safe landing, such that it can be reused without any modification | Visual inspection after landing
MS-04 | The launch vehicle shall be aerodynamically stable at launch rail exit and during flight | Design
FCT-01 | All propulsion systems shall initiate at lift-off | Design
FCT-02 | All propulsion systems shall exclusively use water and either air or nitrogen for pressurization | Design, visual confir-mation during launch pad operations
FCT-03 | If applicable, booster stage shall be discarded at “burnout” (i.e. as soon as no more thrust is generated) | Design
FCT-04 | Maximum pressure allowed for COTS pressure vessels at launch is [7] bar | Design, will be regu-lated by GSE operators
FCT-05 | Max pressure for modified COTS or SRAD pressure vessels at launch is [16] bar | Design, will be regu-lated by GSE operators
FCT-06 | If applicable, core stage and booster stage shall be pressurized at the same pressure value | Design
DGN-01 | Avionics shall be powered only once the launch vehicle is sitting on the launch pad | Design
DGN-02 | Parachute shall be attached/detached to/of the rocket using a metal ring | Design
DGN-03 | If applicable, all booster and core stage shall have their nozzle/water exit at the same height | Design
CONF-01 | The launch vehicle shall be either single stage or 1.5 stage, i.e. 1 core stage or 1 core stage + booster(s) | Design
CONF-02 | If applicable, booster total number shall not be greater than [3] | Design
CONF-03 | If applicable, booster shall be uniformly spread around the core stage | Design
PHY-01 | Airframe/pressure vessels shall possess a standard thread | Design
PHY-03 | The maximum dry mass of the launch vehicle shall be [1.5] kg | Measurement
PHY-04 | The maximum height of the launch vehicle shall be [120] cm | Measurement
SAF-01 | No pyrotechnics (e.g. black powder) shall be used | Design
INT-01 | Launch vehicle shall fit on the launch rail profile | Design, possibility to test-fit beforehand
INT-02 | Propulsion systems shall fit on the GSE pressurization fitting | Design, possibility to test-fit beforehand
VF-01 | All propulsion systems (core stage + boosters if applicable) shall perform at least [one] successful static fire | Test, measurement
VF-02 | All modified COTS pressure vessels shall pass a hydrostatic pressure test at 1.1x the nominal launch pressure | Test, measurement
VF-03 | Calculation/simulation of thrust generated by each stage shall be pro-vided prior to lift-off | Calculation and analysis
VF-04 | Calculation/simulation of flight trajectory of the launch vehicle shall be provided prior to lift-off | Calculation and analysis

Table II
TECHNICAL REQUIREMENTS TO FOLLOW. A GREEN LINE MEANS THAT IT HAS BEEN VERIFIED.
